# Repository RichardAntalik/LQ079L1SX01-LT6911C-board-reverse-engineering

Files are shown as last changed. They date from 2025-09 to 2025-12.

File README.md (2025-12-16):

## LQ079L1SX01 driver board

### Note:
I have removed bunch of components prior to reverse engineering this particular board,
just to check if the STC microcontroller is needed (it did work without it somehow, 
but it is used for powerup sequencing). I have another board, so I will measure the 
components and include these in schematic (when necessary)

### Main driver board:
Component layer
Top layer
Second layer
Third layer
Fourth layer

### Interconnect board:
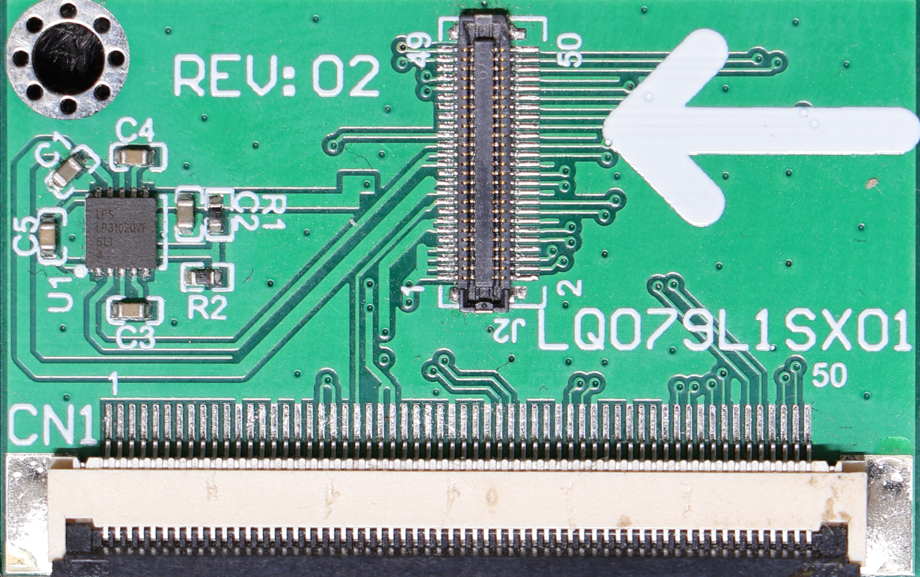
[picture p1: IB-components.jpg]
Second layer

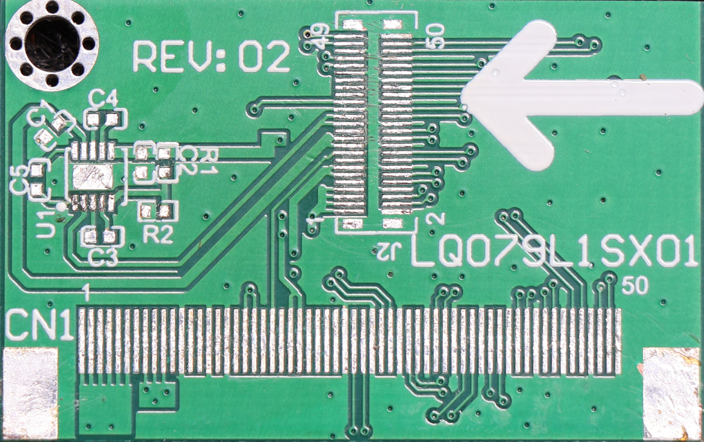
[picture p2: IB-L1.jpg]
Third layer

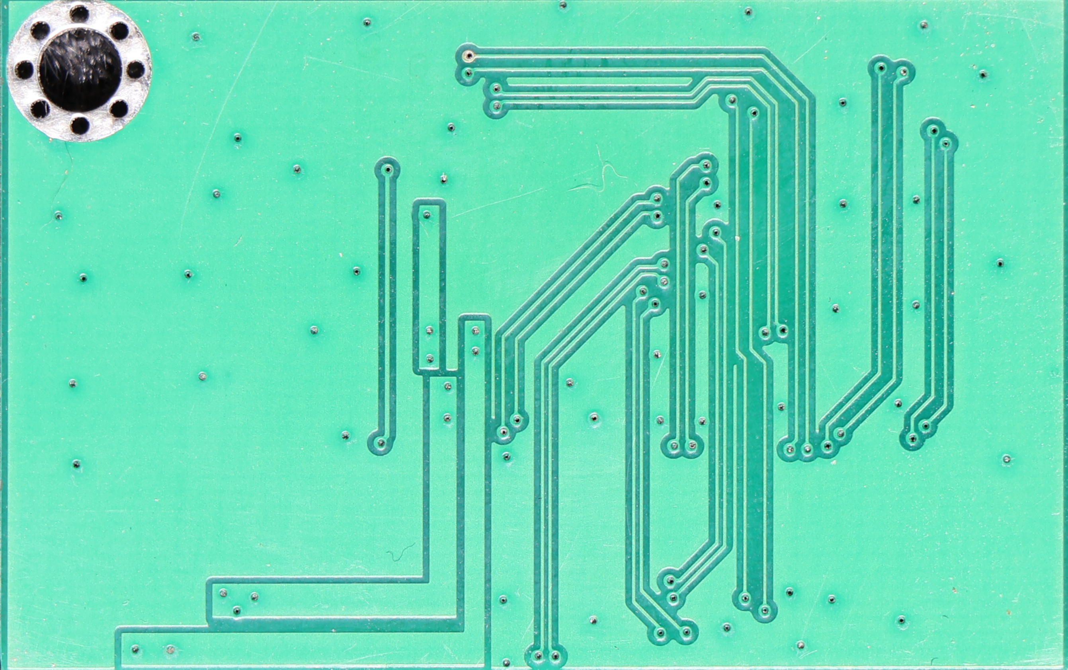
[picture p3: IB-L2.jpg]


### Schematic:
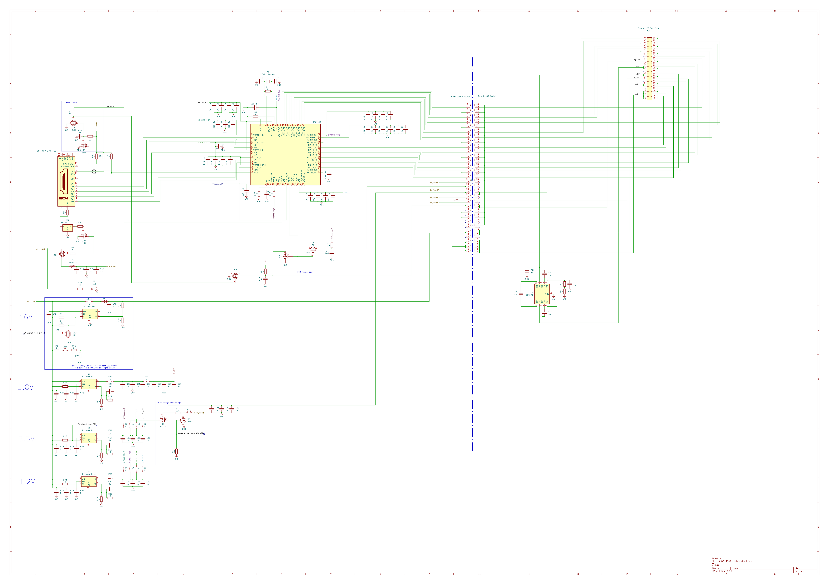
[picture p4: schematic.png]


### Powerup sequence:
#### LT6911C
requires 3.3V rail to raise first, then 1.2V after at least 1ms, finally, reset
is released after at least 1ms. 

3.3V and 1.2V regulators are not sequenced. Reset pin has RC network.
LT6911C emits 3.3V pulse on GPIO5 presumably after reset is released. Presumably after
HDMI communication is established, GPIO 5 emits ~900ms pulse.

#### LQ079L1SX01
requires 1.8V first, 5.6V after 10ms, -5.6V after 10ms, release reset after
20ms, set reset after 10ms, release reset after 10ms, finally 30ms delay before sending
commands.

This sequence is not followed on this board. 1.8V buck converter starts immediately.
Real voltage is above 1.9V. +/-5.6V is generated on small interconnect board.

The reset sequencing is kinda sorta followed, however I am not sure who designed it.
Initial L->H->L pulse is generated by STC chip by enabling and disabling buck converter
for about 30ms.

Then after 2s from time when first pulse is generated, 1.8V rails goes high. This forms
leading edge of second reset pulse. Falling edge is caused by GPIO5 falling down, which
causes Q4 to conduct pulling the rail down.

However reset is active low, so WTF? Well the reset line does not actually go quite down
to 0V. Because Q4 is P channel mosfet, at around 1.2V its resistance will be quite high.
1.2V is out of spec with H or L level for this line.

Finally, there is also Q6, which is able to pull reset line low, when LT6911 does stuff 
with HDMI HPD line, Gate of Q6 is held at ~650mV, which means it is somewhat conducting.
This pulls the line down to about 00mV for the first pulse, and 1.2V for the second
pulse. When GPIO5 goes down, the Therefore line will be held at about 900mV, which is
again out of spec with either H or L level.

Also If I am to follow this powerup sequence from beginning, The first pulse means 
nothing, because whole 1.8V line goes down!

I had some issues with this board, now I think I know why...

#### I2C comms
The I2C bus on LT6911 is not usable by default. The registers are split to banks and the bank is switched by writing to register 0xFF.
Here you can find not only control and status registers, but also firmware, which on my chip started on register 0x10.
The firmware blob is uploaded in this repo as well as hex dump. However I have no idea how to upload the firmware, nor whether it will work.

To enable I2C:
- Switch to 0x80 bank: write 0x80 to register 0xFF on address 0x2B
- Enable the bus: write 0x01 to register 0xEE on address 0x2B
- Disable watchdog: write 0x00 to register 0x10 on address 0x2B

The magic sequence is found in https://github.com/InES-HPMM/Lontium_lt6911uxc/blob/main/source/lt6911uxc_zhaw.c

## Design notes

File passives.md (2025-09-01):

## Main board:
### Resistors:
4.7K R2
4.7K R3
22K  R8
22K  R9
9K   R10
1M   R11
7.6K R12
47K  R13
47K  R14
10K  R15
10K  R16
47K  R20
10K  R21
1K   R22
10K  R23
20K  R24 (Above R25)
10K  R25
10K  R26
22K  R27
100K R28
3R   R31
10K  R32
22K  R33
300K R35
10K  R38
22K  R40
1.5K R45
10K  R48
22K  R49
10K  R55
10K  Under Q12
22K  Resistor between Q8 and Q7

### Decoupling caps:
47, 48, 75, 18, 19, 12, 13, 25, 26, 31, 32, 33, 15, 16, 17, 22, 23, 24, 59, 60, 61, 56, 62, 63, 64, 65, 66, 57, 58, 54, 55, 37, 36, 34, 40, 39, 38, 52, 49, 53, 51, 50, 69, 70, 71
### Unknown caps: 
C21, C77, C76 (all likely 100n), C45 (big one)

### Inductors of interest:
L1-L9 All likely same value

##Interconnect board:
The LP31020VF chip is well documented, but still. 
1K R1
100K R2

R1

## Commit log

2025-09-01 Add schematic and datasheets
    [LQ079L1SX01_driver.kicad_sch]
2025-09-01 Add photos of interconnect board
2025-09-01 Update schematic
    [LQ079L1SX01_driver.kicad_sch]
2025-09-01 Add schematic image
2025-09-06 Fix buck FB
    [LQ079L1SX01_driver.kicad_sch]
2025-12-16 Update I2C comms section in README
    Clarified I2C communication instructions and added enabling steps.
